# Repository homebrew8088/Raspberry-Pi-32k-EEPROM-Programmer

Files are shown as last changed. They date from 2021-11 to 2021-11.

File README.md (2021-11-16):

# Raspberry-Pi-32k-EEPROM-Programmer

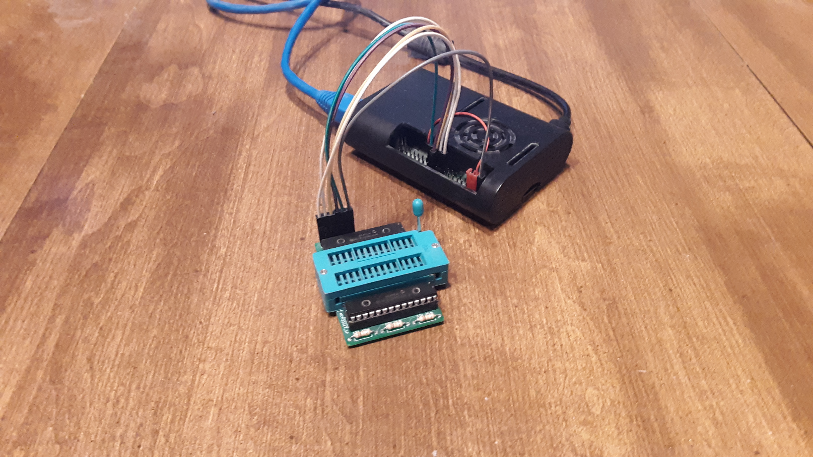
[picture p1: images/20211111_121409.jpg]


\
\
This is a repository for my Rapberry Pi 32k EEPROM Programmer.

The [code](https://github.com/homebrew8088/Raspberry-Pi-32k-EEPROM-Programmer/tree/main/py) is written in python. To run it from the command line type "python3 32k.py"

I have included my [Kicad Files](https://github.com/homebrew8088/Raspberry-Pi-32k-EEPROM-Programmer/tree/main/Kicad) where you can find the schematics and PCB layout.

https://www.homebrew8088.com/home/28c256-eeprom-writer

This was developed to be a cheap alternative for writing 32k EEPROMs for my 8088 projects. You can compile and upload code in the application or just upload a precompiled file.  When using the application to compile the JMP code for an 8088 is automatically inserted at address 0x7FF0.  

The project uses\
1 - Raspberry PI\
2 - MCP23S17 SPI I/O’s\
1 - 28 pin ZIF\
1 - PCB\
3 - 10k resistors 

Trouble shoot \
-make sure SPI is enabled on the raspberry pi \
-install nasm on the raspberry pi

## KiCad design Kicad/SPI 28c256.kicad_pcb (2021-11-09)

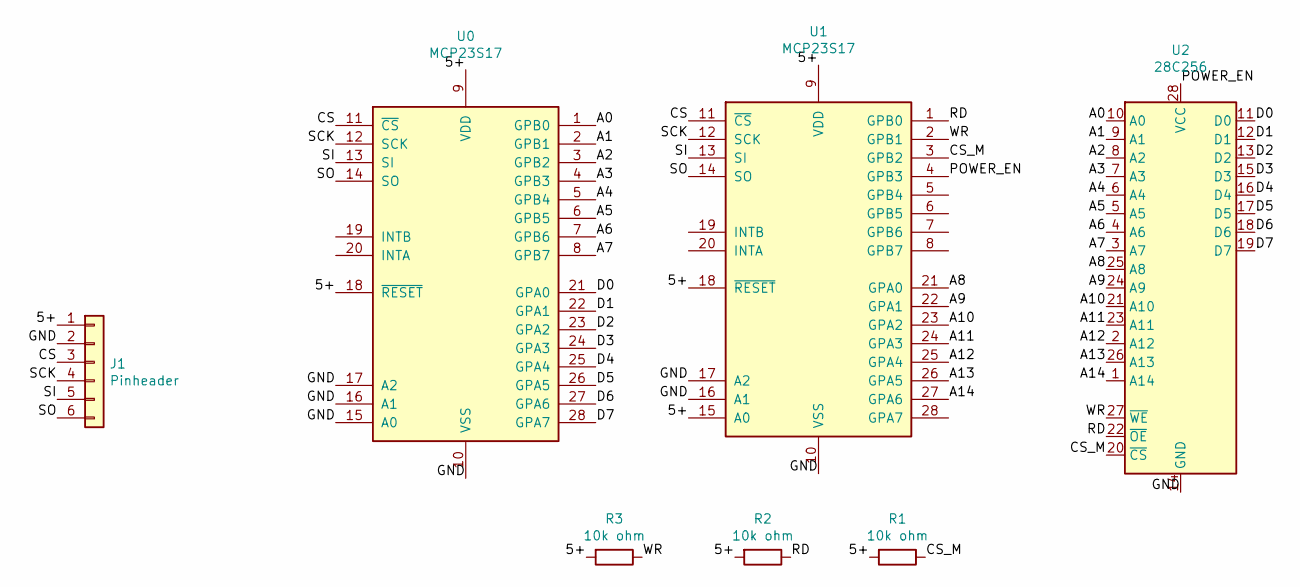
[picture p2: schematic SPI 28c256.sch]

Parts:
J1: Pinheader; PinHeader_1x06_P2.54mm_Vertical
R1, R2, R3: 10k ohm; R_Axial_DIN0207_L6.3mm_D2.5mm_P10.16mm_Horizontal
U0, U1: MCP23S17; DIP-28_W7.62mm
U2: 28C256; DIP_Socket-28_W11.9_W12.7_W15.24_W17.78_W18.5_3M_228-1277-0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

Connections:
/5+: J1.1, R1.2, R2.2, R3.2, U0.9 (VDD), U0.18 (~RESET~), U1.9 (VDD), U1.15 (A0), U1.18 (~RESET~)
/A0: U0.1 (GPB0), U2.10 (A0)
/A1: U0.2 (GPB1), U2.9 (A1)
/A2: U0.3 (GPB2), U2.8 (A2)
/A3: U0.4 (GPB3), U2.7 (A3)
/A4: U0.5 (GPB4), U2.6 (A4)
/A5: U0.6 (GPB5), U2.5 (A5)
/A6: U0.7 (GPB6), U2.4 (A6)
/A7: U0.8 (GPB7), U2.3 (A7)
/A8: U1.21 (GPA0), U2.25 (A8)
/A9: U1.22 (GPA1), U2.24 (A9)
/A10: U1.23 (GPA2), U2.21 (A10)
/A11: U1.24 (GPA3), U2.23 (A11)
/A12: U1.25 (GPA4), U2.2 (A12)
/A13: U1.26 (GPA5), U2.26 (A13)
/A14: U1.27 (GPA6), U2.1 (A14)
/CS: J1.3, U0.11 (~CS~), U1.11 (~CS~)
/CS_M: R1.1, U1.3 (GPB2), U2.20 (~CS)
/D0: U0.21 (GPA0), U2.11 (D0)
/D1: U0.22 (GPA1), U2.12 (D1)
/D2: U0.23 (GPA2), U2.13 (D2)
/D3: U0.24 (GPA3), U2.15 (D3)
/D4: U0.25 (GPA4), U2.16 (D4)
/D5: U0.26 (GPA5), U2.17 (D5)
/D6: U0.27 (GPA6), U2.18 (D6)
/D7: U0.28 (GPA7), U2.19 (D7)
/GND: J1.2, U0.10 (VSS), U0.15 (A0), U0.16 (A1), U0.17 (A2), U1.10 (VSS), U1.16 (A1), U1.17 (A2), U2.14 (GND)
/POWER_EN: U1.4 (GPB3), U2.28 (VCC)
/RD: R2.1, U1.1 (GPB0), U2.22 (~OE)
/SCK: J1.4, U0.12 (SCK), U1.12 (SCK)
/SI: J1.5, U0.13 (SI), U1.13 (SI)
/SO: J1.6, U0.14 (SO), U1.14 (SO)
/WR: R3.1, U1.2 (GPB1), U2.27 (~WE)

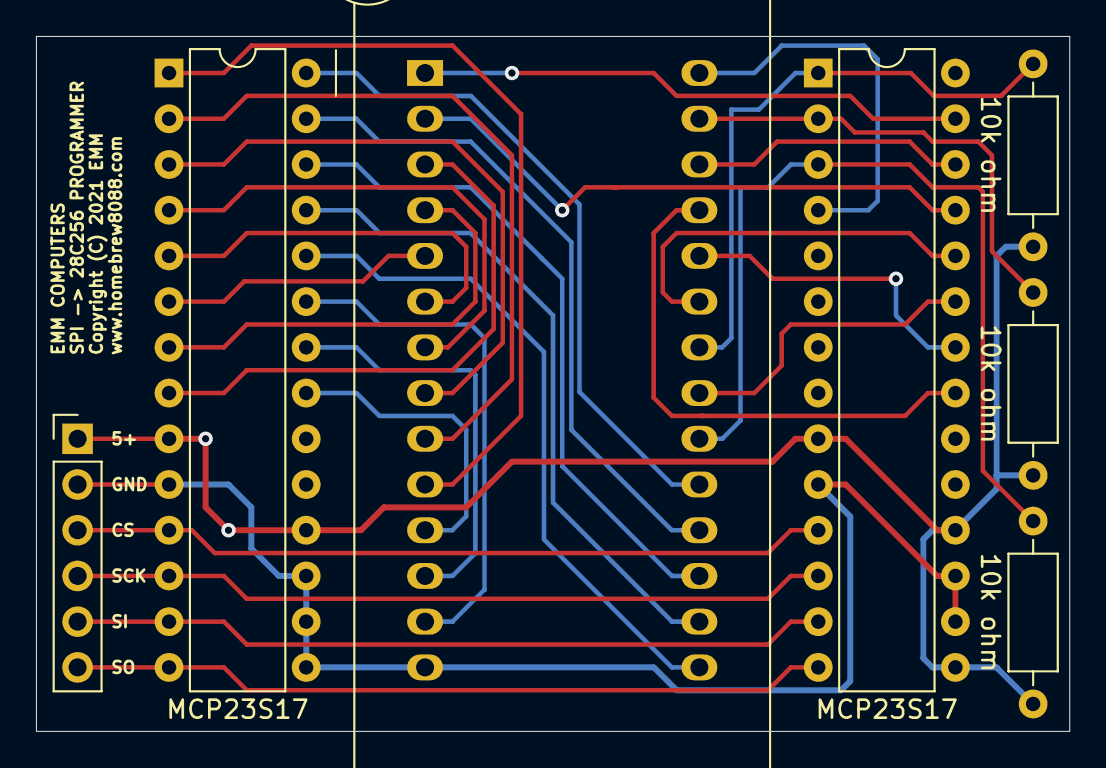
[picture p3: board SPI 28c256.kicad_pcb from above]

Board: 2 copper layers, 57.4 x 38.6 mm, 7 parts (0 on the bottom side), 33 nets.

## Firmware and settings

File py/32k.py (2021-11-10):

#pyinstaller --onefile --hidden-import tkinter new.py

from tkinter import *
from tkinter import filedialog
from tkinter import messagebox
import os
from os import system

import SPI32k

def donothing():
   print("Hello World")

def new_file():
    text_field.delete(1.0,END)
    main_window.title("32K 28C256 Writer")
    main_window.file_and_path = ''

def open_file():
    file_name = filedialog.askopenfilename(initialdir = "/home/pi",title = "Open",filetypes = (("Assembly","*.asm"),("all files","*.*")))
    if file_name:
        file_open = open(file_name)
        file_data = file_open.read()
        file_open.close()
        text_field.delete(1.0,END)
        text_field.insert(END, file_data)
        main_window.file_and_path = file_name
        main_window.title("32K 28C256 Writer " + main_window.file_and_path)

def save_file():
    if(main_window.file_and_path == ''):
        file_save = filedialog.asksaveasfile(mode='w', initialdir = "/home/pi",title = "Save",filetypes = (("Assembly","*.asm"),("all files","*.*")))
        if file_save:
            file_save.write(text_field.get(1.0,END))
            main_window.file_and_path = file_save.name
            main_window.title("32K 28C256 Writer " + main_window.file_and_path)
            file_save.close()
    else:
        file_save = open(main_window.file_and_path, 'w')
        file_save.write(text_field.get(1.0,END))
        file_save.close()

def save_as_file():
        file_save = filedialog.asksaveasfile(mode='w', initialdir = "/home/pi",title = "Save As",filetypes = (("Assembly","*.asm"),("all files","*.*")))
        if file_save:
            file_save.write(text_field.get(1.0,END))
            main_window.file_and_path = file_save.name
            main_window.title("32K 28C256 Writer " + main_window.file_and_path)
            file_save.close()

def Upload_File():
    file_name = filedialog.askopenfilename(initialdir = "/home/pi",title = "Open",filetypes = (("compiled x86 code","*.bin *.rom"),("all files","*.*")))
    if file_name:
        file_open = open(file_name, mode='rb')
        file_data = file_open.read()
        file_open.close()
        
    SPI32k.Write_Memory_Array(0x0000, file_data)
    print(file_name + " DONE")
    
def Compile_and_Upload():
    if(main_window.file_and_path == ''):
        messagebox.showinfo("Compiler Error", "File not open or saved!")

    else:
        file_save = open(main_window.file_and_path, 'w')
        file_save.write(text_field.get(1.0,END))
        file_save.close()

        main_window.file_and_path_bin = main_window.file_and_path[:-4] + '.bin'
        os.system("nasm " + main_window.file_and_path + ' -o ' + main_window.file_and_path_bin)

        if os.path.exists(main_window.file_and_path[:-4] + '.bin'):
            file_open = open(main_window.file_and_path[:-4] + '.bin', mode='rb')
            file_data = file_open.read()
            file_open.close()

            Jump_code = [0XEA, 0X00, 0X00, 0X00, 0XF8, 0X45, 0X4D, 0X4D, 0X00, 0X00, 0X00, 0X00, 0X00, 0X00, 0X00, 0X00]

            SPI32k.Write_Memory_Array(0xFFF0, Jump_code)
            print("JUMP CODE DONE JMP 0XF800:0X0000")
            SPI32k.Write_Memory_Array(0x0000, file_data)
            print("CODE DONE AT ADDRESS 0X0000")


        else:
            messagebox.showinfo("Compiler Error", "bin file was not compiled check NASM output for errors")

def Compile_code():
    if(main_window.file_and_path == ''):
        messagebox.showinfo("Compiler Error", "File not open or saved!")
    else:
        file_save = open(main_window.file_and_path, 'w')
        file_save.write(text_field.get(1.0,END))
        file_save.close()

        main_window.file_and_path_bin = main_window.file_and_path[:-4] + '.bin'
        os.system("nasm " + main_window.file_and_path + ' -o ' + main_window.file_and_path_bin)

        if os.path.exists(main_window.file_and_path[:-4] + '.bin'):
            print("COMPILE COMPLETE")  
        else:
            messagebox.showinfo("Compiler Error", "bin file was not compiled check NASM output for errors")
            
def Read_Back():
    print("JUMP CODE")
    SPI32k.Read_Memory_Array(0xFFFF0, 16)

# Create the main window
main_window = Tk()
main_window.title("32K 28C256 Writer")
main_window.minsize(800, 600)



menubar = Menu(main_window)
filemenu = Menu(menubar, tearoff=0)
filemenu.add_command(label="New", command=new_file)
filemenu.add_command(label="Open", command=open_file)
filemenu.add_command(label="Save", command=save_file)
filemenu.add_command(label="Save As", command=save_as_file)
filemenu.add_separator()
filemenu.add_command(label="Exit", command=main_window.destroy)
menubar.add_cascade(label="File", menu=filemenu)

buildmenu = Menu(menubar, tearoff=0)
buildmenu.add_command(label="Compile -> Upload", command=Compile_and_Upload)
buildmenu.add_command(label="Compile", command=Compile_code)
buildmenu.add_command(label="Read Back 0xFFFF0", command=Read_Back)
buildmenu.add_command(label="Upload File", command=Upload_File)
menubar.add_cascade(label="Build", menu=buildmenu)

main_window.config(menu=menubar)

main_window.file_and_path = ''
main_window.file_and_path_bin = ''

text_field = Text(main_window)
#text_field.wrap (WORD)
text_field.pack(expand=True, fill='both')
# Run forever!
scrollbar = Scrollbar(text_field)
scrollbar.pack( side = RIGHT, fill = Y )


SPI32k.Start_SPI()

main_window.mainloop()

SPI32k.spi.close()

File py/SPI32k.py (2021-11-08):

import spidev
import time

MCP23S17_WRITE_00 = 0b01000000
MCP23S17_READ_00 =  0b01000001
MCP23S17_WRITE_01 = 0b01000010
MCP23S17_READ_01 =  0b01000011


IOCON_0A = 0x0A
IODIRA = 0x00
IODIRB = 0x01
GPIOA = 0x12;
GPIOB = 0X13;
ALL_OUT = 0x00;
ALL_IN = 0xFF;

spi = spidev.SpiDev()


def Start_SPI():
    spi.open(0, 0)
    spi.max_speed_hz = 10000000

    #Enable address pins
    spi.xfer([MCP23S17_WRITE_01, IOCON_0A, 0b00001000])
    #Setup ports
    #8 bit Data
    spi.xfer([MCP23S17_WRITE_00, IODIRA, ALL_OUT])
    #Address 0-7
    spi.xfer([MCP23S17_WRITE_00, IODIRB, ALL_OUT])
    #Address 8-15
    spi.xfer([MCP23S17_WRITE_01, IODIRA, ALL_OUT])
    #Control Port
    spi.xfer([MCP23S17_WRITE_01, IODIRB, ALL_OUT])
    
    spi.xfer([MCP23S17_WRITE_01, GPIOB, 0b00000111]) 


def Read_Memory_Array(Address, Count):
    #8 bit Data out put
    spi.xfer([MCP23S17_WRITE_00, IODIRA, ALL_IN])
    #Turn on power
    spi.xfer([MCP23S17_WRITE_01, GPIOB, 0b00001111])
    time.sleep(1/100)
    oAddress = Address
    while Address < (oAddress + Count):
        spi.xfer([MCP23S17_WRITE_00, GPIOB, Address])
        spi.xfer([MCP23S17_WRITE_01, GPIOA, Address >> 8])
        spi.xfer([MCP23S17_WRITE_01, GPIOB, 0b00001010])
        val = spi.xfer([MCP23S17_READ_00, GPIOA, 0x00])
        spi.xfer([MCP23S17_WRITE_01, GPIOB, 0b00001111]) 
        print(hex(val[2]))
        Address += 1
    time.sleep(1/100)
    #Turn off power
    spi.xfer([MCP23S17_WRITE_01, GPIOB, 0b00000111])
    
    
    
def Write_Memory_Array(Address, code_for_8088):
    #8 bit Data out put
    spi.xfer([MCP23S17_WRITE_00, IODIRA, ALL_OUT])
    #Turn on power
    spi.xfer([MCP23S17_WRITE_01, GPIOB, 0b00001111])
    time.sleep(1/100)
    for i in code_for_8088:
        spi.xfer([MCP23S17_WRITE_00, GPIOB, Address])
        spi.xfer([MCP23S17_WRITE_01, GPIOA, Address >> 8])
        spi.xfer([MCP23S17_WRITE_00, GPIOA, i])
        time.sleep(1/100)
        spi.xfer([MCP23S17_WRITE_01, GPIOB, 0b00001001])
        time.sleep(1/100)
        spi.xfer([MCP23S17_WRITE_01, GPIOB, 0b00001111])
        print("Writing Adress" + hex(Address) + " Byte" + hex(i) )
        Address += 1
    time.sleep(1/100)
    #Turn off power
    spi.xfer([MCP23S17_WRITE_01, GPIOB, 0b00000111]) 

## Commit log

2021-11-09 Added Kicad Files
    [SPI 28c256-B_Cu.gbr, SPI 28c256-B_Mask.gbr, SPI 28c256-B_Paste.gbr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]
2021-11-09 Fixed Label
    [SPI 28c256.kicad_pcb]

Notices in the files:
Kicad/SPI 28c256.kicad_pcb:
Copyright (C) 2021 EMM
